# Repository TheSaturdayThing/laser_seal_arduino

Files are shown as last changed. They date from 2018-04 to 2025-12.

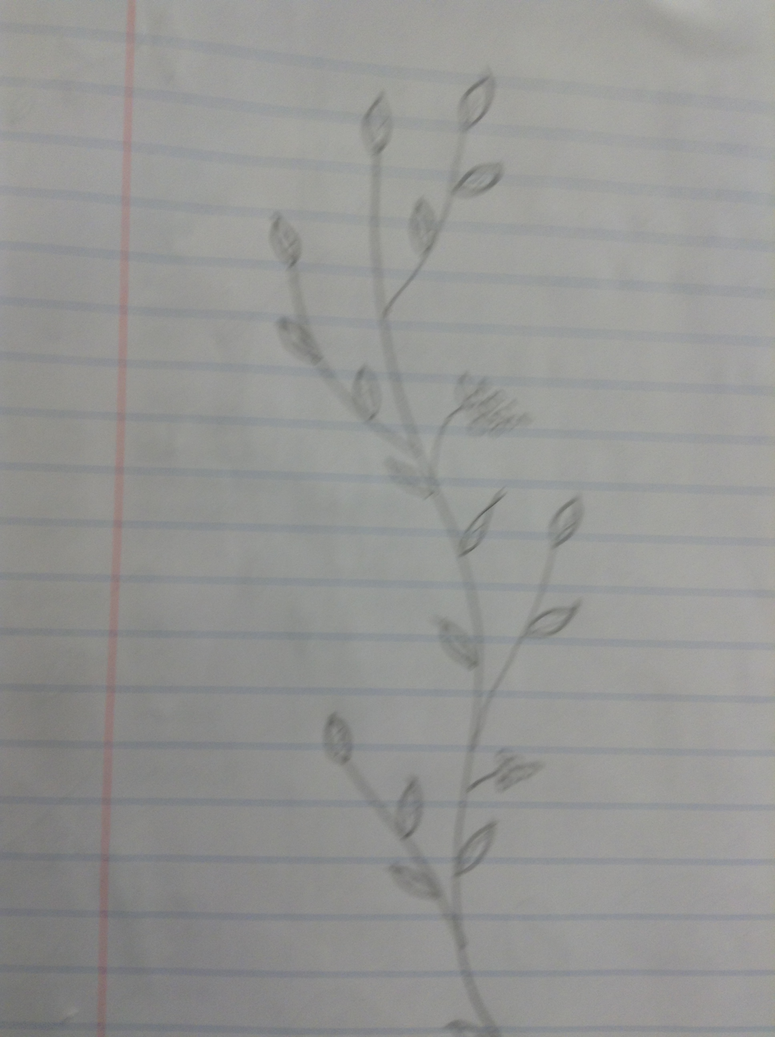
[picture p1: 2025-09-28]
laser_cutter_files/VineDrawing.jpg

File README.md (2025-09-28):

# laser_seal_arduino
## Folder Contents
   * Sketches (arduino programs)
   * Libraries (providing extra functionality for use in sketches)
   * Help Guides
   * Laser cutter files (used to manufacture the seal)
## If you haven't used Git and GitHub before, you may find these guides helpful:
   * https://guides.github.com/
## Working with files in this Git repository can be done 
   * on the GitHub website
   * from the command line on your local system
   * with GUI apps like 'GitHub Desktop' or 'GitKraken':
     * https://desktop.github.com/
     * https://www.gitkraken.com/
## When creating folders in this project, please include a 'README.md' file explaining the contents.
   * For help with the'markdown' syntax for .md files, see either the included cheatsheet above or the on-line tutorial below:
     * https://guides.github.com/features/mastering-markdown/

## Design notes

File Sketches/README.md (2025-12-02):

Arduino code (sketches)
* photocell
* piezo
* MIDI_Harp_Pentatonic_MP3Shield.ino -- firmware for the Arduino from Daniel Sheen (may or may not be current revision)
* R4-midi: selectable musical instrument
  * Written for Arduino R4 Minima (uses sensors on 8 digital inputs)
  * Sparkfun instrument shield (no SD card)
  * Arduino Modulino I2C control knob
  * Sunfounder I2C 4-line LCD display

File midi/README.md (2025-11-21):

The Laser Seal uses an Arduino to control a [SparkFun MP3 Player Shield](https://www.sparkfun.com/sparkfun-mp3-player-shield.html).  
This board utilizes the VS1053 MP3 audio decoder IC to decode audio files.

The current implementation does *NOT* use the VS1053 to play MP3 files, but instead it is set to real-time MIDI by activating the "Real-Time MIDI mode":
- GPIO0 is LOW (grounded through 100K resistor on shield)
- GPIO1 is HIGH (driven by pin D4 of shield)
  
Once activated, the VS1053 can receive MIDI data through the UART (at a 31250 bps MIDI baud rate) or via the SPI bus, allowing it to function as a synthesizer without needing to load a MIDI file. 

Real-time MIDI data is transmitted as a series of messages, each starting with a status byte indicating the message type, followed by one or two data bytes containing specific information like note, velocity, or channel. Key real-time messages include System Real-Time messages for synchronization (e.g., Start, Stop, Timing Clock), which have status bytes but no data bytes. Other common real-time data includes standard messages like Note On/Off, which include a status byte for the message and channel, and data bytes for note number and velocity. 

The current laser seal uses a MIDI [instrument](https://fmslogo.sourceforge.io/manual/midi-instrument.html) code of '**12: Chromatic Percussion/ Marimba**' on the default channel 0 and follows a 17-note pentatonic scale with a velocity of 60 (medium loudness):  
PENTA_NOTES[NUM_STRINGS] = {24, 26, 28, 31, 33, 36, 38, 40, 43, 45, 48, 50, 52, 55, 57, 60, 62};  
(see [here](https://inspiredacoustics.com/en/MIDI_note_numbers_and_center_frequencies))

| Sensor | MIDI | Piano Key |Note | Frequency (HZ) |
|---|---|---|-----|---|
| 1 | 24 | 4 | C1  | 32.70 |
| 2 | 26 | 6 | D1  | 36.71 |
| 3 | 28 | 8 | E1  | 41.20 |
| 4 | 31 | 11 | G1  | 49.00 |
| 5 | 33 | 13 | A1  | 55.00 |
| 6 | 36 | 16 | C2  | 65.41 |
| 7 | 38 | 18 | D2  | 73.42 |
| 8 | 40 | 20 | E2  | 82.41 |
| 9 | 43 | 23 | G2  | 98.00 |
| 10 | 45 | 25 | A2  | 110.00 |
| 11 | 48 | 28 | C3  | 130.81 |
| 12 | 50 | 30 | D3  | 146.83 |
| 13 | 52 | 32 | E3  | 164.81 |
| 14 | 55 | 35 | G3  | 196.00 |
| 15 | 57 | 37 | A3  | 220.00 |
| 16 | 60 | 40 | C4  | 261.63 |
| 17 | 62 | 42 | D4  | 293.66 |

An explanation of MIDI messaging is [here](https://learn.sparkfun.com/tutorials/midi-tutorial/all)

Support for the current v1.03.00 libraries is on [github.io](https://mpflaga.github.io/Arduino_Library-vs1053_for_SdFat/index.html) and explains how the board is set up.

Driver source code can be found [here](https://github.com/mpflaga/Arduino_Library-vs1053_for_SdFat)

This was migrated from the now closed v1.02.15 page on [github.com](https://mpflaga.github.io/Sparkfun-MP3-Player-Shield-Arduino-Library) along with the older [source code](https://github.com/mpflaga/Sparkfun-MP3-Player-Shield-Arduino-Library)

Documentation on the VS1053 chip can be found on the manufacturer's [website](https://www.vlsi.fi/en/products/vs1053.html)

TODO:
- Does the current Mega take into account that the Arduino Uno uses digital pins 11 (MOSI), 12 (MISO), and 13 (SCK) for hardware SPI, while the Arduino Mega uses 51 (MOSI), 50 (MISO), and 52 (SCK). 
- Both boards have a separate pin for slave select (SS), which is pin 10 on the Uno and pin 53 on the Mega.

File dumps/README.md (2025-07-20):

The **readfile.hex** file is from the Arduino Mega2560 in the Laser Seal.
By saving a copy, we can use it to restore the code to the Mega if it ever gets corrupted.
We can also attempt to reverse-engineer the code as a last resort using [Ghidra](https://en.wikipedia.org/wiki/Ghidra) or [IDA Pro](https://en.wikipedia.org/wiki/Interactive_Disassembler)

**avrdude** (AVR Downloader UploaDE) is a program for downloading and uploading the on-chip memories of Microchip’s AVR microcontrollers. It can program the Flash and EEPROM, and where supported by the programming protocol, it can program fuse and lock bits. AVRDUDE also supplies a direct instruction mode allowing one to issue any programming instruction to the AVR chip regardless of whether AVRDUDE implements that specific feature of a particular chip.

https://github.com/avrdudes/avrdude

The Arduino IDE uses **avrdude** to program the Arduino, but can also be used to read the binary code stored on it.

[https://forum.arduino.cc/t/downloading-existing-code/872624](https://forum.arduino.cc/t/downloading-existing-code/872624/12)

For the Arduino Mega, the code was read by running:

* sudo ./avrdude "-C/Users/david/Library/Arduino15/packages/arduino/tools/avrdude/6.3.0-arduino17/etc/avrdude.conf" -v -V -patmega2560 -cwiring "-P/dev/cu.usbmodem101" -b115200 -D "-Uflash:r:readfile.hex:i"

where options are  
-C: config file  
-v: verbose mode  
-V: Disable automatic verify check when uploading data  
-p: part number, atmega2560
-c: programmer (the Mega is a type of "wiring" board, an earlier protyping product)    
-P: port  
-b: baud rate  
-D: disable pre-erase  
-U: memory operation  
  
* flash: This specifies the memory region to be accessed, which is the microcontroller's flash memory.
* r: This indicates a read operation, meaning the contents of the flash memory will be read.
* readfile.hex: This is the file name where the flash memory contents will be saved.
* i: The output file (readfile.hex) should be in the Intel Hex format. 

Results when reading the flash out to **readfile.hex**

===============================================

avrdude: Version 6.3-20190619  
         Copyright (c) 2000-2005 Brian Dean, http://www.bdmicro.com/  
         Copyright (c) 2007-2014 Joerg Wunsch  

         System wide configuration file is "/Users/david/Library/Arduino15/packages/arduino/tools/avrdude/6.3.0-arduino17/etc/avrdude.conf"
         User configuration file is "/Users/david/.avrduderc"
         User configuration file does not exist or is not a regular file, skipping

         Using Port                    : /dev/cu.usbmodem101
         Using Programmer              : wiring
         Overriding Baud Rate          : 115200
         AVR Part                      : ATmega2560
         Chip Erase delay              : 9000 us
         PAGEL                         : PD7
         BS2                           : PA0
         RESET disposition             : dedicated
         RETRY pulse                   : SCK
         serial program mode           : yes
         parallel program mode         : yes
         Timeout                       : 200
         StabDelay                     : 100
         CmdexeDelay                   : 25
         SyncLoops                     : 32
         ByteDelay                     : 0
         PollIndex                     : 3
         PollValue                     : 0x53
         Memory Detail                 :

                                  Block Poll               Page                       Polled
           Memory Type Mode Delay Size  Indx Paged  Size   Size #Pages MinW  MaxW   ReadBack
           ----------- ---- ----- ----- ---- ------ ------ ---- ------ ----- ----- ---------
           eeprom        65    10     8    0 no       4096    8      0  9000  9000 0x00 0x00
           flash         65    10   256    0 yes    262144  256   1024  4500  4500 0x00 0x00
           lfuse          0     0     0    0 no          1    0      0  9000  9000 0x00 0x00
           hfuse          0     0     0    0 no          1    0      0  9000  9000 0x00 0x00
           efuse          0     0     0    0 no          1    0      0  9000  9000 0x00 0x00
           lock           0     0     0    0 no          1    0      0  9000  9000 0x00 0x00
           calibration    0     0     0    0 no          1    0      0     0     0 0x00 0x00
           signature      0     0     0    0 no          3    0      0     0     0 0x00 0x00

         Programmer Type : Wiring
         Description     : Wiring
         Programmer Model: AVRISP
         Hardware Version: 15
         Firmware Version Master : 2.10
         Vtarget         : 0.0 V
         SCK period      : 0.1 us

avrdude: AVR device initialized and ready to accept instructions

Reading | ################################################## | 100% 0.01s

avrdude: Device signature = 0x1e9801 (probably m2560)  
avrdude: safemode: lfuse reads as 0  
avrdude: safemode: hfuse reads as 0  
avrdude: safemode: efuse reads as 0  
avrdude: reading flash memory:  

Reading | ################################################## | 100% 33.46s

avrdude: writing output file "readfile.hex"

avrdude: safemode: lfuse reads as 0  
avrdude: safemode: hfuse reads as 0  
avrdude: safemode: efuse reads as 0  
avrdude: safemode: Fuses OK (E:00, H:00, L:00)  

avrdude done.  Thank you.

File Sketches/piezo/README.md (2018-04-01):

Noisemaker that changes frequency based on light level.
* See https://blog.adafruit.com/2009/05/19/piezo-with-an-arduino-photoresistor/

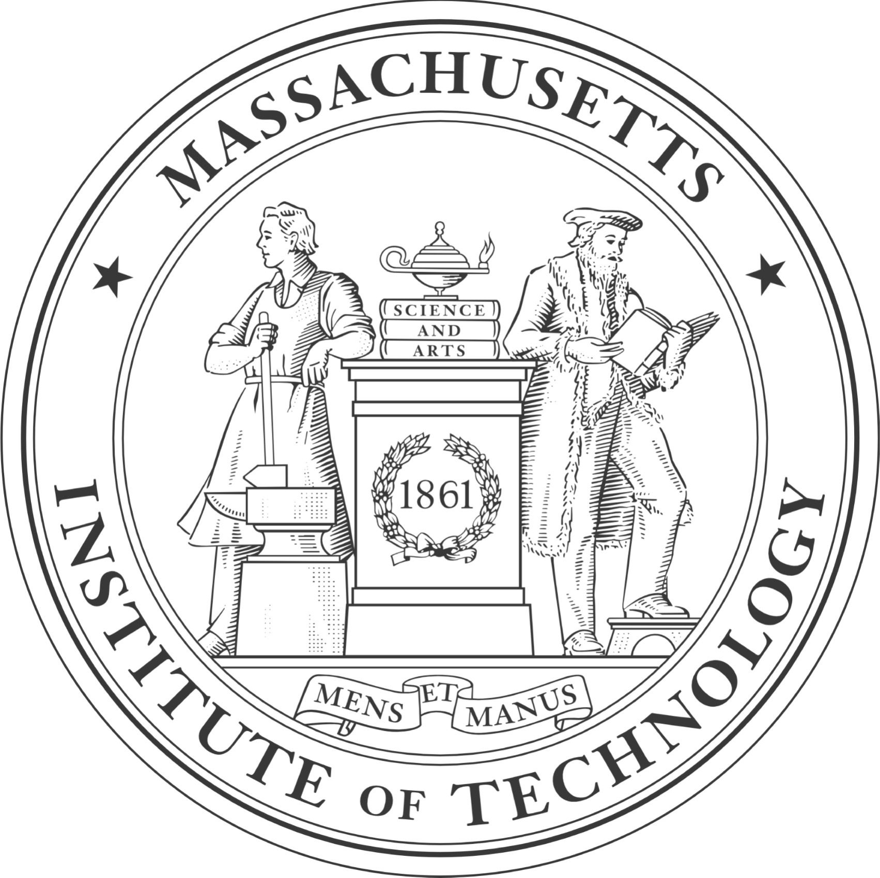
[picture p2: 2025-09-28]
laser_cutter_files/MIT_Crest_Vectorized_ACD_0.jpg

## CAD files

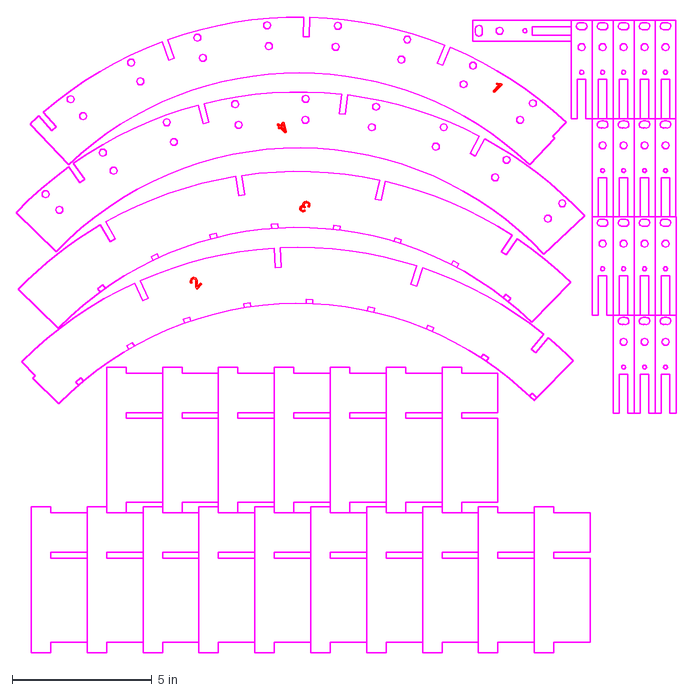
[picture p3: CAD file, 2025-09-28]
laser_cutter_files/laser circle cut files/laser circle final sheet one.dxf
23.6 x 22.8 in

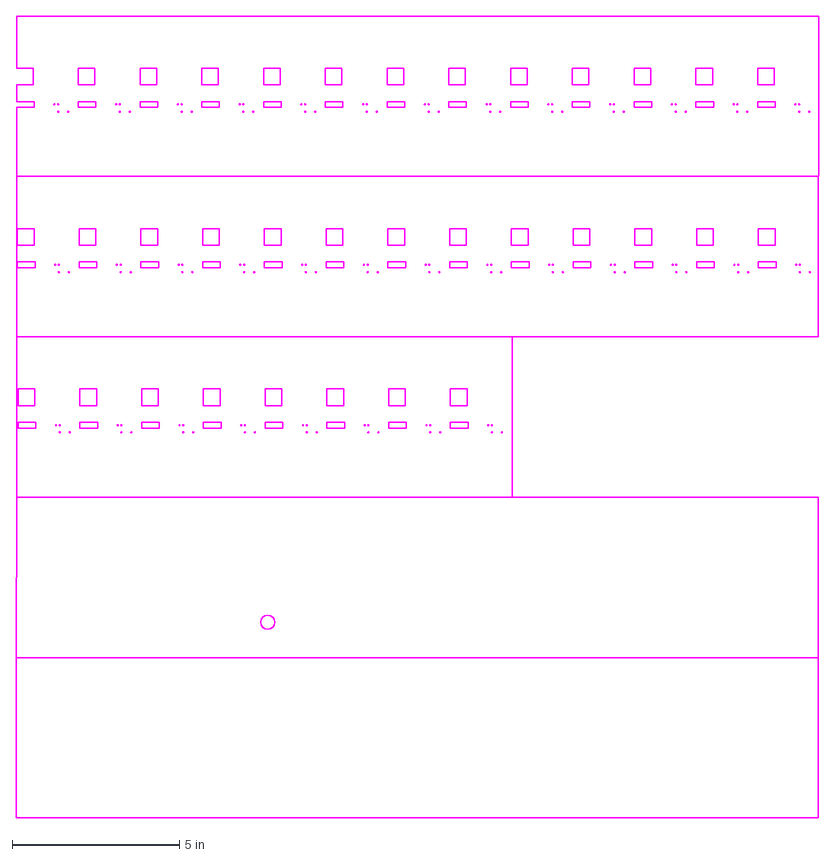
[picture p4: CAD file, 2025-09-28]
laser_cutter_files/laser circle cut files/petg pieces sheet one.dxf
24.0 x 24.0 in

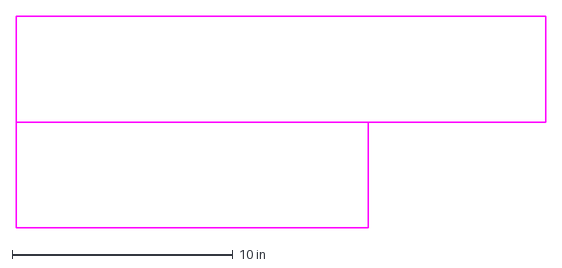
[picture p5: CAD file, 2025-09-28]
laser_cutter_files/laser circle cut files/petg pieces sheet two.dxf
24.0 x 9.60 in

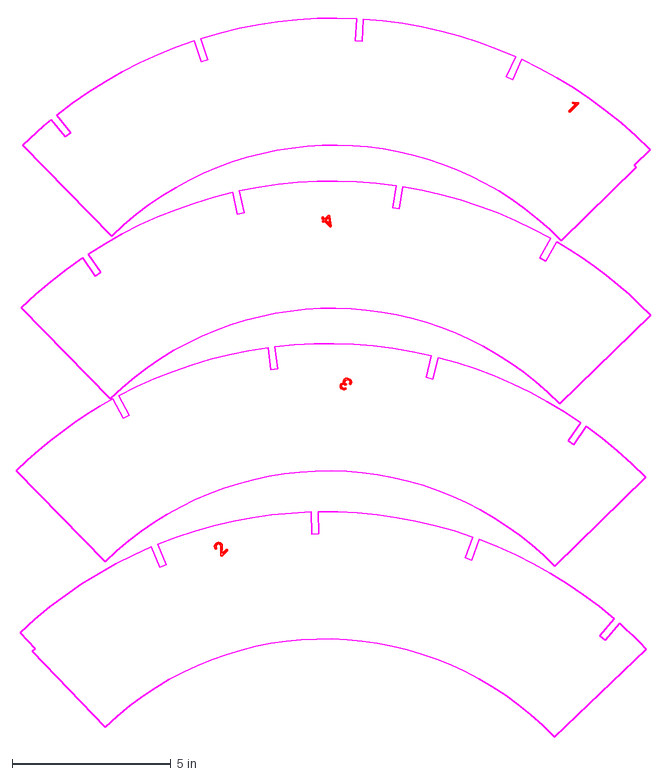
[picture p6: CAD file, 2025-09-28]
laser_cutter_files/laser circle cut files/laser circle final sheet two.dxf
20.0 x 22.7 in

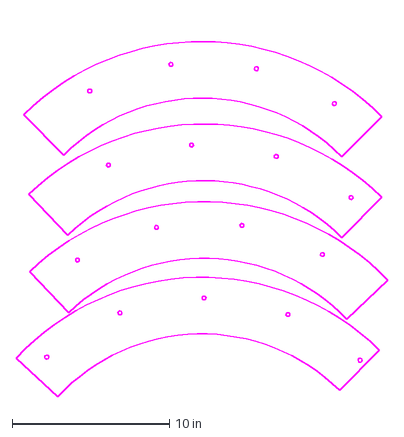
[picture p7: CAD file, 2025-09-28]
laser_cutter_files/laser circle sheet two.dxf
23.6 x 24.2 in

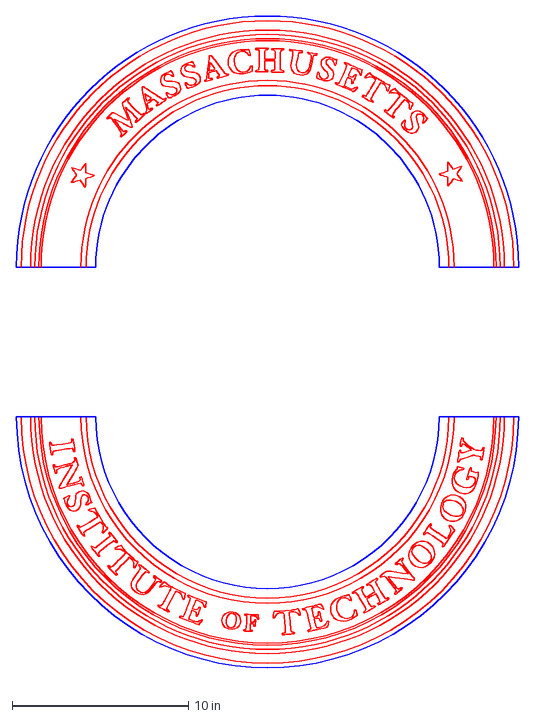
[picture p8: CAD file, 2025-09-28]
laser_cutter_files/laser circle cut files/engraving.dxf
28.5 x 37.6 in

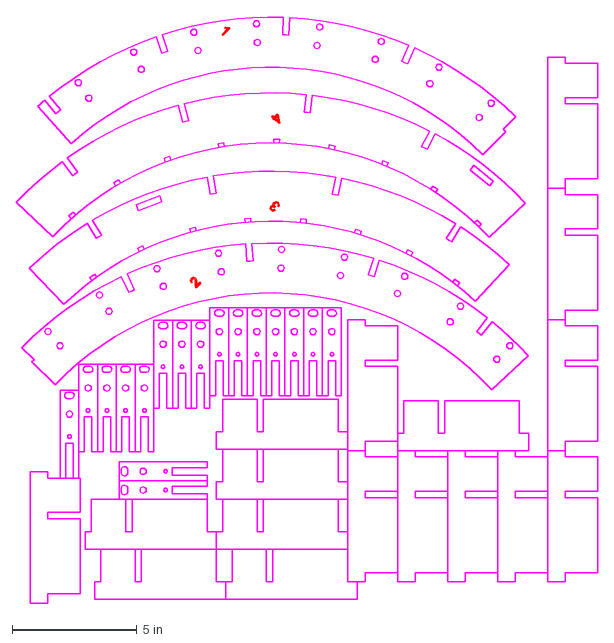
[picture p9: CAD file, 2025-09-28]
laser_cutter_files/laser circle final sheet one.dxf
23.3 x 23.5 in

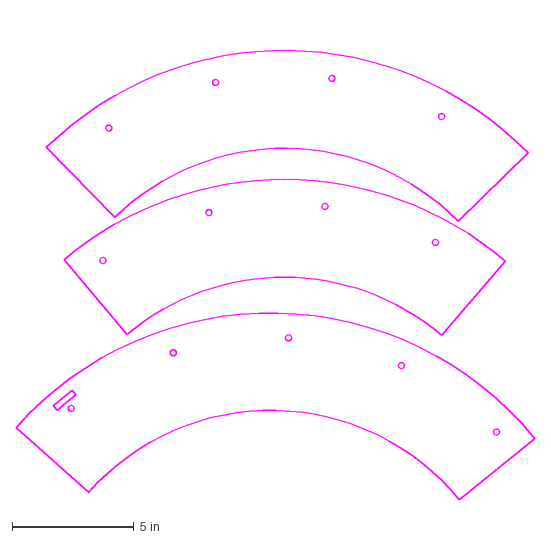
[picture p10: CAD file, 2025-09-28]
laser_cutter_files/laser circle 28 inch sheet 2.dxf
21.3 x 19.9 in

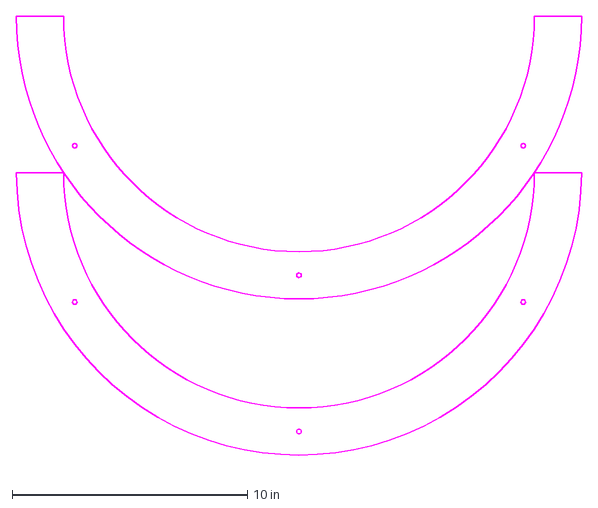
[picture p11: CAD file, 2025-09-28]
laser_cutter_files/laser circle cut files/petg support ring.dxf
24.0 x 19.2 in

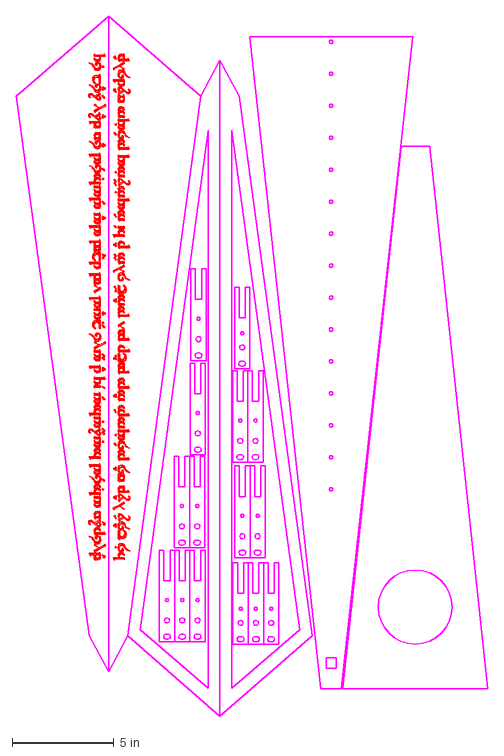
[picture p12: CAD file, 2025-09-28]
laser_cutter_files/laser harp 3 sheet one.dxf
23.1 x 34.4 in

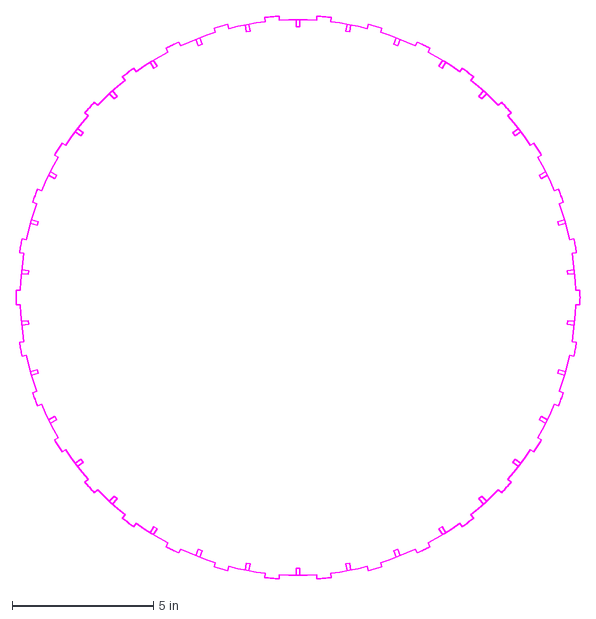
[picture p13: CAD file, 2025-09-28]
laser_cutter_files/laser circle cut files/laser circle seal center.dxf
20.0 x 20.0 in

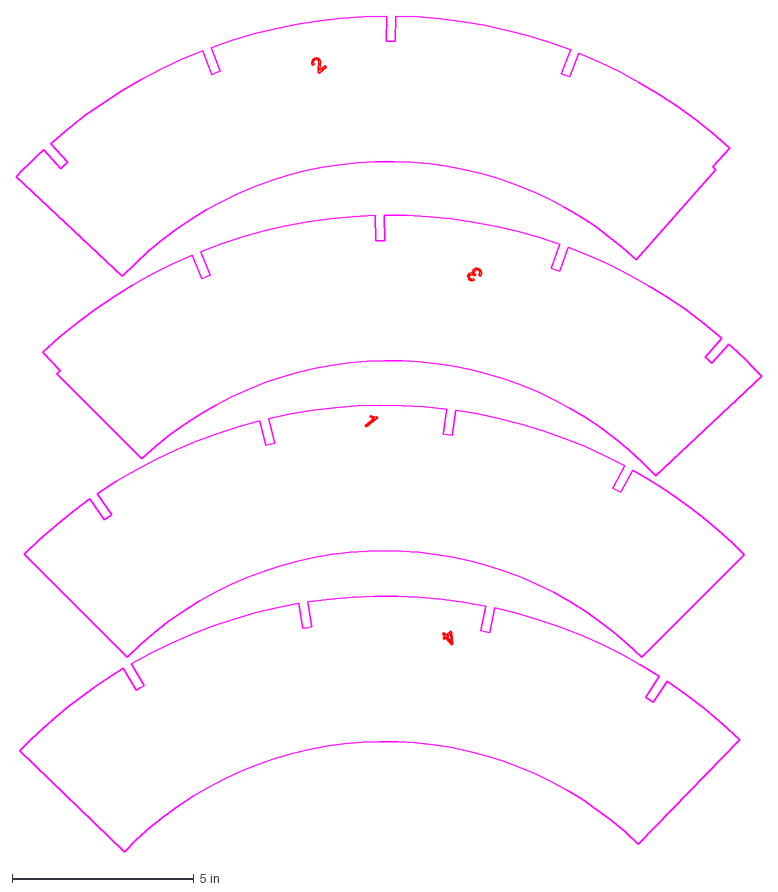
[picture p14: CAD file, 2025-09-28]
laser_cutter_files/laser circle final sheet two.dxf
20.5 x 23.0 in

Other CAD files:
laser_cutter_files/laser harp 3.dxf
laser_cutter_files/Drawing5.dwg
laser_cutter_files/base piece.dwg
laser_cutter_files/laser circle cut files/petg pieces.dwg
laser_cutter_files/laser harp 4.dwg
laser_cutter_files/laser harp 3 vines.dxf
laser_cutter_files/LASER CIRCLE FINAL.dwg
laser_cutter_files/MIT_Crest_Vectorized.dwg
laser_cutter_files/MIT_Crest_Vectorized.dxf
laser_cutter_files/OldVersions/laser circle 3D.0001.ipt
laser_cutter_files/OldVersions/laser circle assembly.0005.iam
laser_cutter_files/back layer of front.ipt
laser_cutter_files/laser circle 28 inch sheet one.dxf
laser_cutter_files/laser circle 28 inch.dwg
laser_cutter_files/laser circle 28 inch.dxf
laser_cutter_files/laser circle 3D.ipt
laser_cutter_files/laser circle assembly.iam
laser_cutter_files/laser circle cut files/petg support ring.dwg
laser_cutter_files/laser circle final sheet two.dwg
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

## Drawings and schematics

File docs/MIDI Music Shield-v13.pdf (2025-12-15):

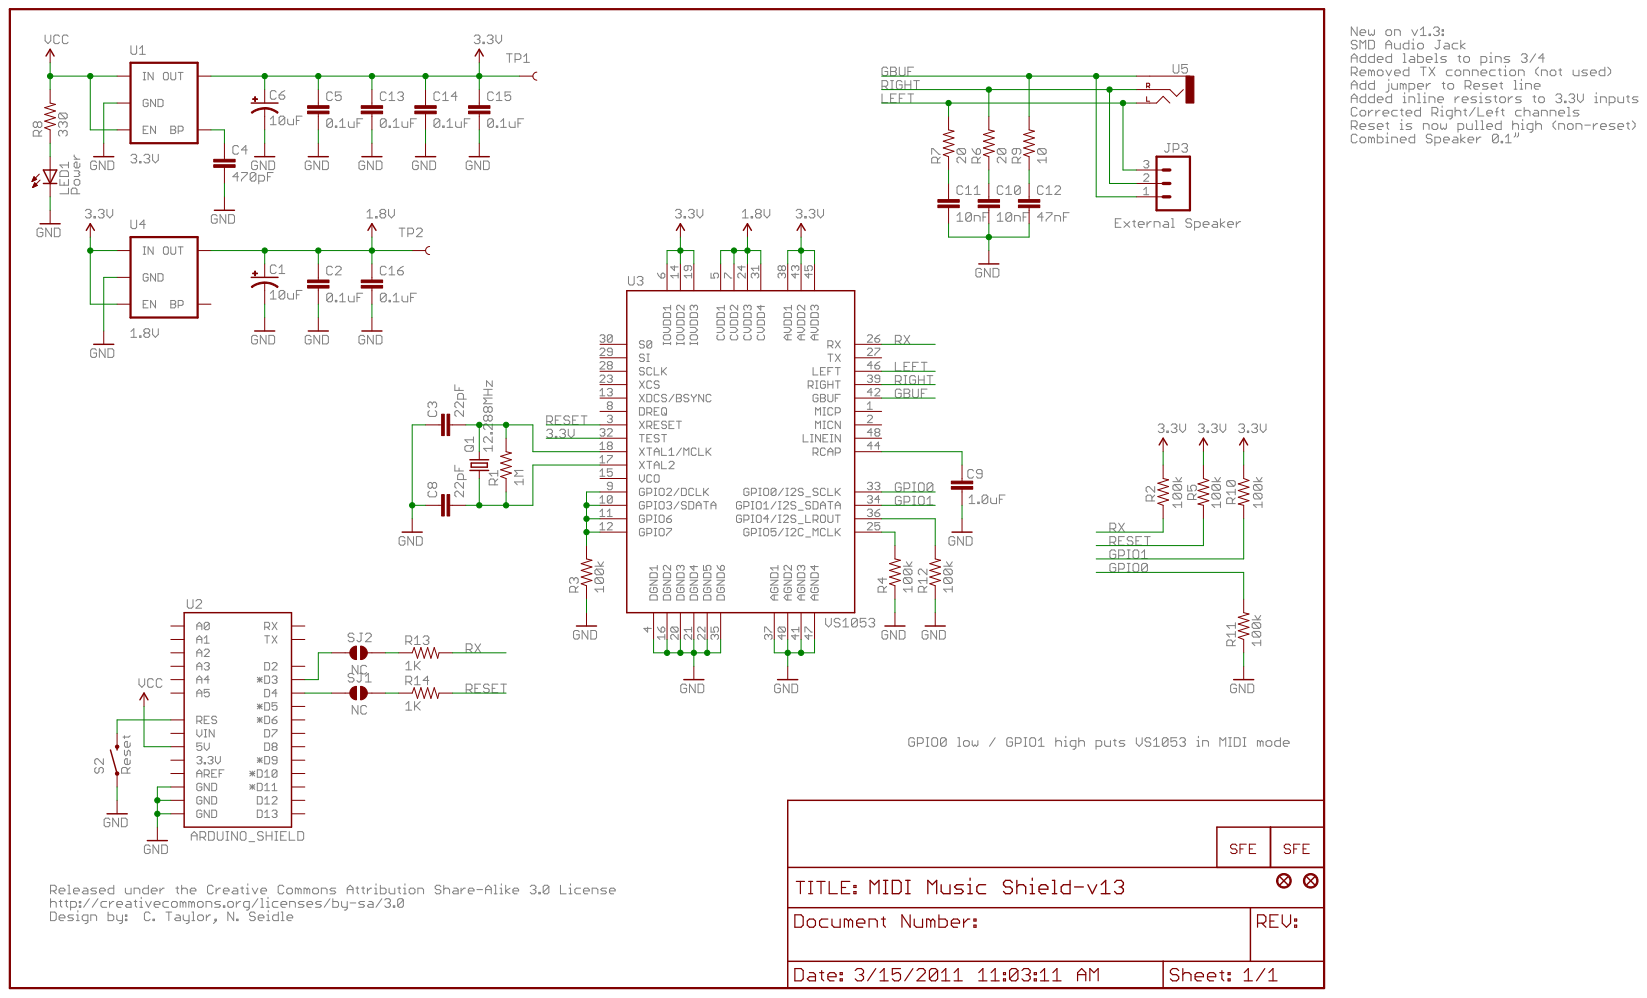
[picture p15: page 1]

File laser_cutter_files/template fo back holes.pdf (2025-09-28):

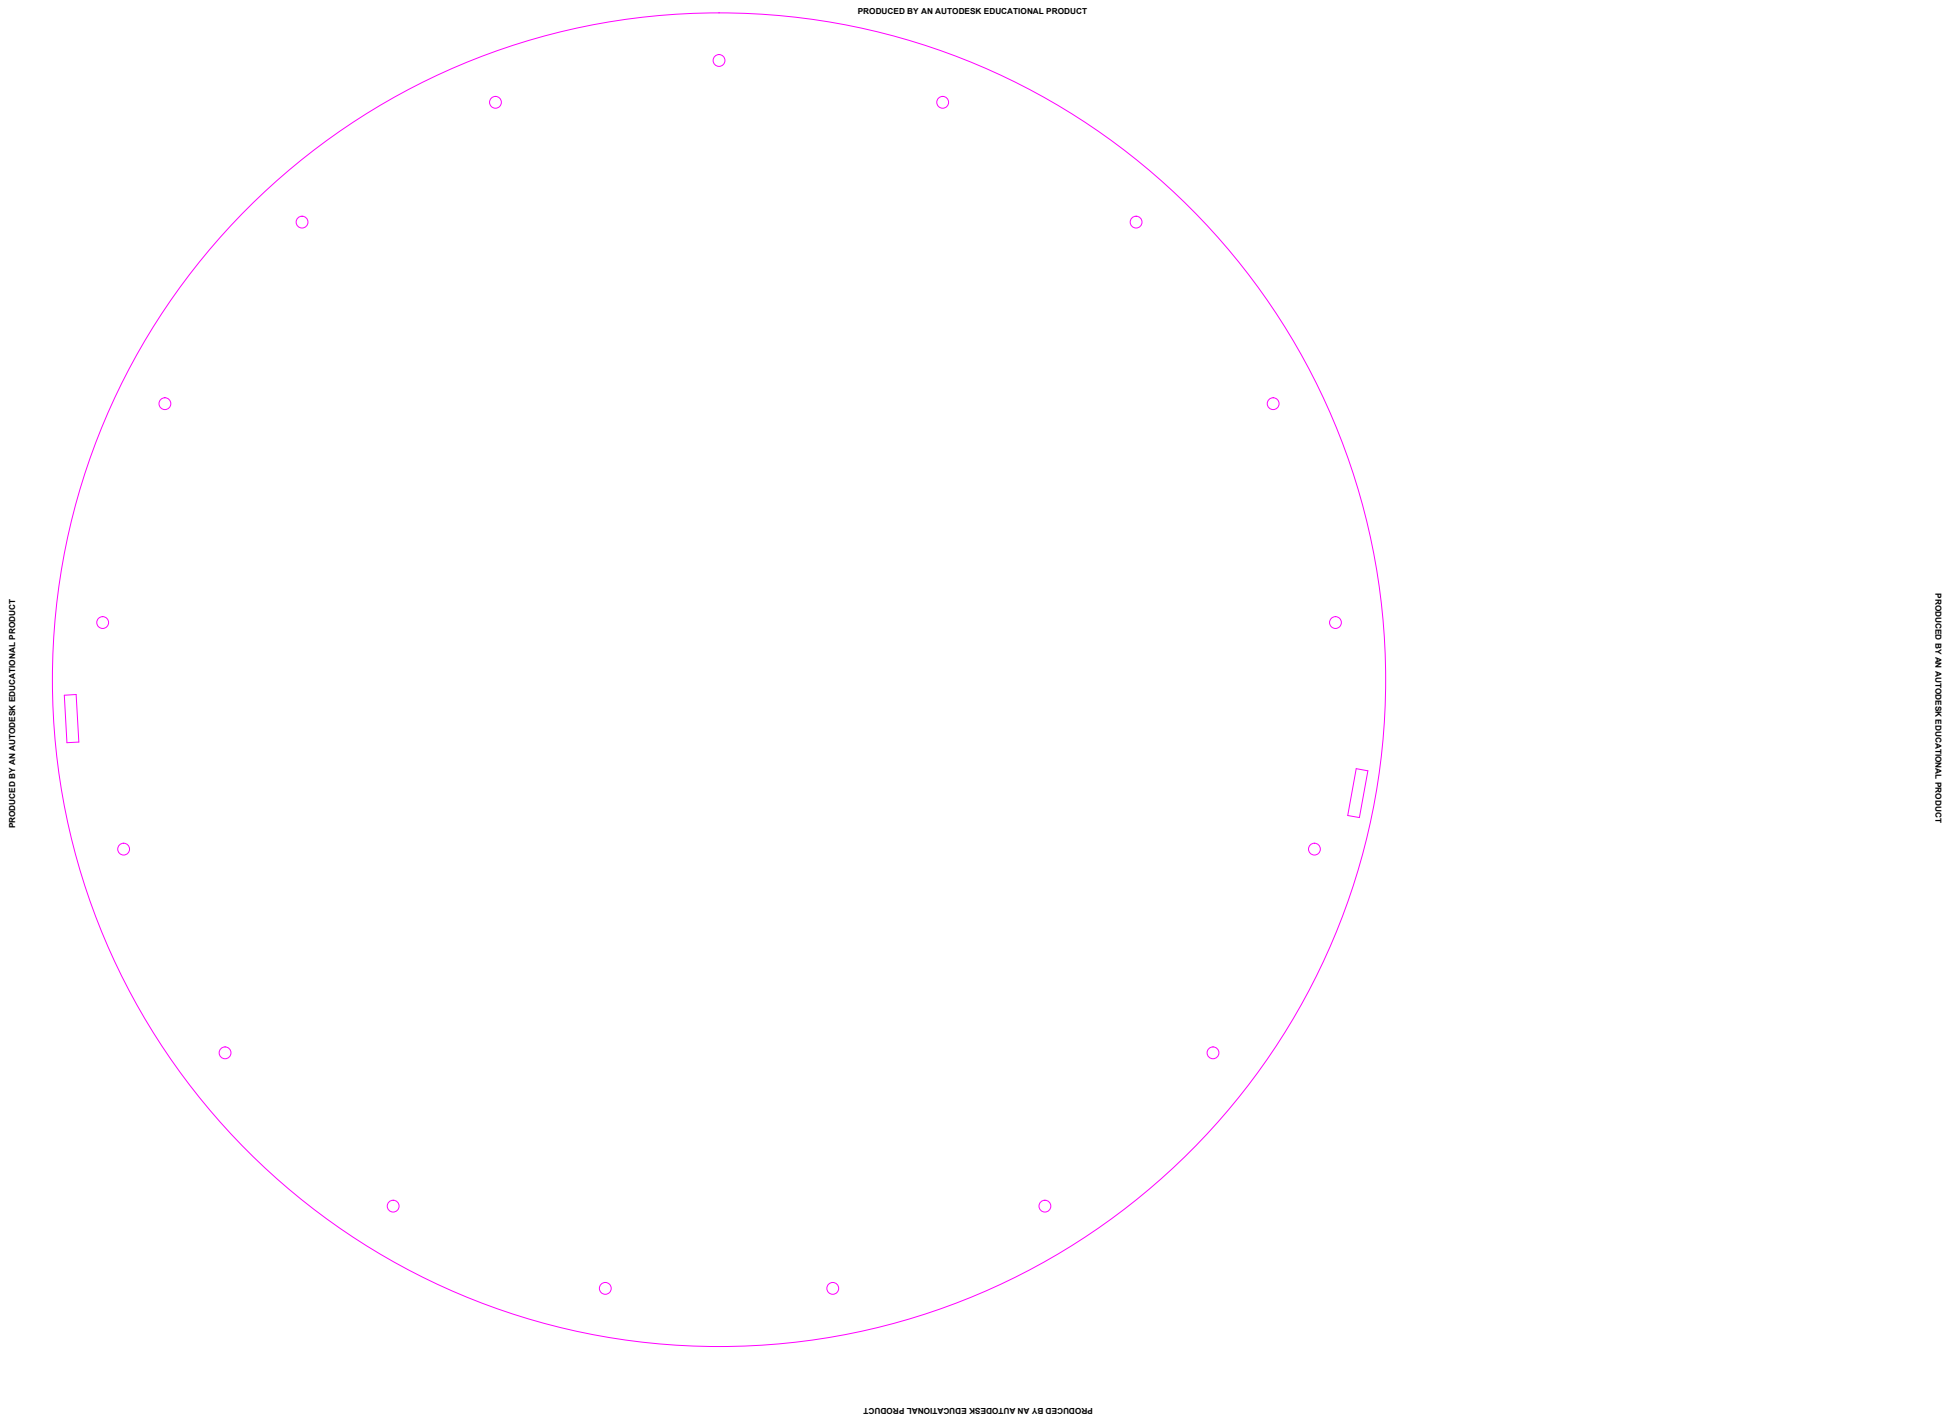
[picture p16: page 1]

PRODUCED BY AN AUTODESK EDUCATIONAL PRODUCT

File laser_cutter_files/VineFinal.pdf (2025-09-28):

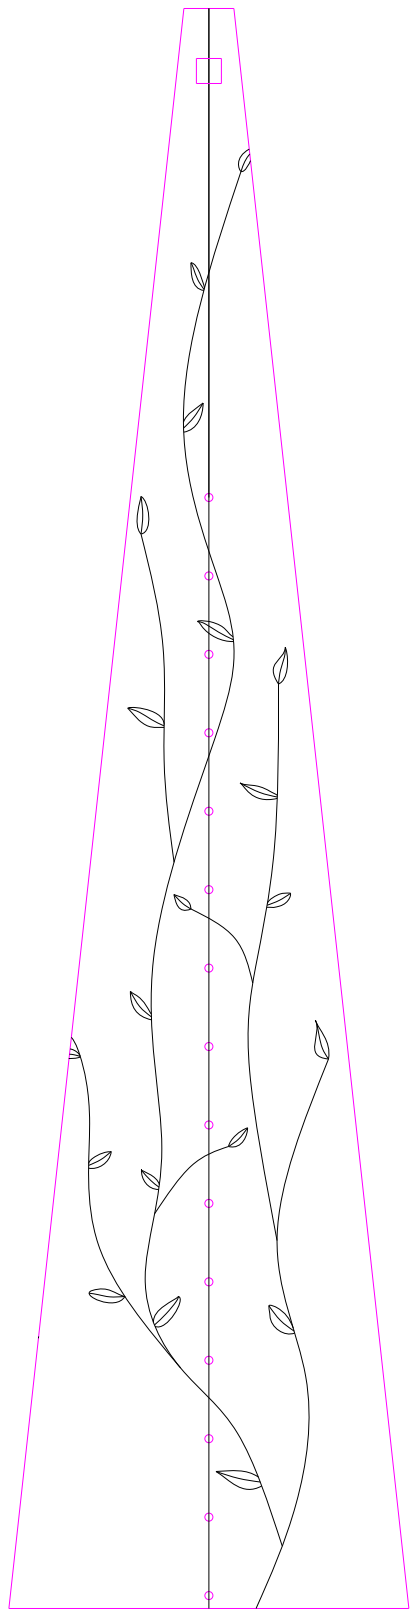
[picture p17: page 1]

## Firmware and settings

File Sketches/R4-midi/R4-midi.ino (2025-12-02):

/*
MIDI Harp, with new MP3 Shield
======================

David Iwatsuki November 22, 2025
Revised for Arduino R4 Minima with simplified SparkFun MIDI Music Instrument Shield v13
Which is pre-configured on the board to operate in Real Time MIDI mode

Product: https://www.sparkfun.com/sparkfun-music-instrument-shield.html
GitHub: https://github.com/sparkfun/Music_Instrument_Shield

The Uno R4 has 14 digital pins and 6 analog pins

D0,D1 Serial Monitor RX/TX

D2 (SoftSerial RX) : floating on shield
D3 (SoftSerial TX) : VS1053 RX
D4 : VS1053 RESET
D13 : LED indicator

D5 - D12 availble (8 pins)
A0 - A3 available (4 pins) 

A4, A5 used for I2C peripheral comms

On the R4, the default mode for digital pins is 'input'

======================

Revised and Revamped, Jake Barnwell, July 3-4 2013:
Updated from legacy code (with iRig and iPhone) by Erin King, Ed Moriarty, Jake Barnwell.
See Jake Barnwell for a copy of legacy code for old hardware, and all comments thereof.
  
This is the code for using the new MP3 shield for the Arduino. Said shield precludes the need
for the iRig to iPhone hassle; instead the MP3 shield outputs straight to the speaker.

Useful link is still useful: www.phys.unsw.edu.au/jw/notes.html

Final Code (Only for laser harp versions 1 and 2), Jake Barnwell, July 9 2013:  
Completed edits to make the harp more or less vibration proof. I have instated a minimum
shade time requirement (10 milliseconds)--if the sensor is not shaded for at least 10 ms,
the note will not trigger. This prevents small vibrations from button-mashing the 
proverbial keyboard. Large vibrations (e.g. hammer smashes) will still trigger them.

*/

#include <SoftwareSerial.h>
#include "Knob.h"
#include "LCD.h"
#include "Midi_db.h"

/* Begin MIDI declarations */

SoftwareSerial mySerial(2, 3);  //RX pin defaults to input, TX pin set to output

const int resetMIDI = 4; //Chip reset be driven by Arduino
const int ledPin = 13;   //Drive LED on Arduino board as MIDI traffic inidicator

byte chanMsg_bankSelect = 0x00;
byte chanMsg_noteOff = 0x80;
byte chanMsg_noteOn = 0x90;
byte chanMsg_controlChange = 0xb0;
byte chanMsg_program = 0xc0; //This one is used to switch instruments
byte chanMsg_pitchWheel = 0xe0;

byte bank_default = 0;
byte bank_drums1 = 0x78;
byte bank_melodic = 0x79; //Default bank is usually GM1 (melodic)
byte bank_drums2 = 0x7f;

byte channelVolume = 0x07; //Use as parameter with chanMsg_controlChange
byte devControl_masterVolume = 0x01;

/* End MIDI declarations */
/* Begin music and pin declarations */

//Define Arduino R4's digital input pins for strings:
//Pins are {5,6,7,8,9,10,11,12,13}
const int STRING_PINS[] = {5,6,7,8,9,10,11,12}; // Pins D5-D12
const int NUM_STRINGS = sizeof(STRING_PINS) / sizeof(STRING_PINS[0]); // Calculate number of pins

//Define notes in arrays. The numbers are MIDI-specifiers for the given notes.
//e.g. 33 is A1 (A, 2nd octave)
const int MAJOR_NOTES[NUM_STRINGS] = {23, 24, 26, 28, 29, 31, 33, 35};
const int PENTA_NOTES[NUM_STRINGS] = {24, 26, 28, 31, 33, 36, 38, 40};

int stringVals[NUM_STRINGS]; //Holds the readings from the pins in the current round
boolean previouslyOn[NUM_STRINGS]; //True if the pin was on in the last round; false otherwise
boolean noteIsOn[NUM_STRINGS]; //True if the note is playing for the string
unsigned int signalOnTimes[NUM_STRINGS]; //Holds time at which each string was triggered, if on

/* End music declarations */
/* Begin options: */

const int minShadeTime = 10; //Minimum shade time for a note: 10 milliseconds.

int knob_read = 0;
int instrument = 12; // Piano: marimba. Make this user selectable
int channel = 0;     // First channel
int velocity = 60;
int volume = 120;

/* End options */

void setup() {
  //Begin Serial Monitor for debug: 
  Serial.begin(9600);
  Serial.println("STARTING");
 
  // Init knob on I2C
  initKnob();
  
  // Init LCD display
  initLCD();

  //Begin MIDI Serial for MIDI control: chip requires 31,250
  mySerial.begin(31250);
  
  //Terminate digital inputs if not connected
  pinMode(2, INPUT_PULLUP); //Enable pullup since RX pin from shield to Arduino is not used

  for (int i = 0; i < NUM_STRINGS; i++) {
    pinMode(STRING_PINS[i], INPUT_PULLUP); //Loop to enable pullup on sensor pins

    Serial.print("Pin ");
    Serial.print(STRING_PINS[i]);
    Serial.println(" set to INPUT_PULLUP");
  }
  //Resets the VS1053:
  pinMode(resetMIDI, OUTPUT); // declare Arduino pin as output
  digitalWrite(resetMIDI, LOW);
  delay(100);
  digitalWrite(resetMIDI, HIGH);
  delay(100);
  Serial.println("MIDI reset");
  
  //Set channel volume, max is 127
  talkMIDI(chanMsg_controlChange, channelVolume, volume);
}
/* End setup */

void loop() {
  //Read instrument value from knob and send to MIDI shield
  
  instrument = readKnobPos(); //FIX ME: instrument change during scan causes multiple voices
  Serial.println(instrument);
  talkMIDI(chanMsg_program, instrument, channel); //Set instrument number.
  
  //Display MIDI info on LCD
  displayMidi(instrument);

  //Take sensor pin readings in this round:
  for (int i = 0; i < NUM_STRINGS; i++) {
    stringVals[i] = digitalRead(STRING_PINS[i]);
  }
  
  //Process readings (play note when digital pin goes HIGH):
  for (int i = 0; i < NUM_STRINGS; i++) {
    if (stringVals[i] == HIGH && previouslyOn[i] == true) {
      if (millis() - signalOnTimes[i] >= minShadeTime) {
        if (noteIsOn[i] == false) {
          noteOn(channel, PENTA_NOTES[i], velocity); //Note plays when shaded (?check circuit design?)
          noteIsOn[i] = true;
        }
      }
    } else if (stringVals[i] == HIGH && previouslyOn[i] == false) {
      signalOnTimes[i] = millis();
    } else if (stringVals[i] == LOW && previouslyOn[i] == true) {
      noteOff(channel, PENTA_NOTES[i], velocity);
      noteIsOn[i] = false;
      signalOnTimes[i] = 0;
    } else {
      ;
    }
    
    //When all is done, assign current values to past values:
    previouslyOn[i] = stringVals[i]; //Booleans typecast, T = 1, F = 0
  }
}

// Functions are below
//
//Talks MIDI. Doesn't check to see that cmd is greater than 127, or that data values are less than 127
void talkMIDI(byte cmd, byte data1, byte data2) {
  digitalWrite(ledPin, HIGH);
  mySerial.write(cmd);
  mySerial.write(data1);

  //Some commands only have one data byte. All cmds less than 0xBn have 2 data bytes 
  //(sort of: http://253.ccarh.org/handout/midiprotocol/)
  if( (cmd & 0xF0) <= 0xB0)
    mySerial.write(data2);
  digitalWrite(ledPin, LOW);
}

//Send a MIDI note-on message.
void noteOn(byte chan, byte note, byte attack_velocity) {
  talkMIDI( (chanMsg_noteOn | chan), note, attack_velocity);
}

//Send a MIDI note-off message.
void noteOff(byte chan, byte note, byte release_velocity) {
  talkMIDI( (chanMsg_noteOff | chan), note, release_velocity);
}

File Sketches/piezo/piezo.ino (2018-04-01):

int photosensorPin = 0;
int piezoPin = 9;

int val = 0;

void setup() {
  pinMode(piezoPin, OUTPUT);
}

void loop() {
  digitalWrite(piezoPin, LOW);
  val = analogRead(photosensorPin);
  val = val/2;

  for( int i=0; i// play it for 50 cycles
    digitalWrite(piezoPin, HIGH);
    delayMicroseconds(val);
    digitalWrite(piezoPin, LOW);
    delayMicroseconds(val);
  }
}
